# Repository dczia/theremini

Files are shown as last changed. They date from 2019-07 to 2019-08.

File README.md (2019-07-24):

# Theremini

What's better than a laser theremin?  How about a laser theremin SAO?!

This SAO unfortunately does not make any noise or produce lasers, but it does have:

 - Microchip AVR attiny1616 8-bit microcontroller
 - 5 touch-sensitive buttons
 - 6 red LEDs arranged about the tape spool holes
 - Reprogrammable via UPDI via the SAO connector!

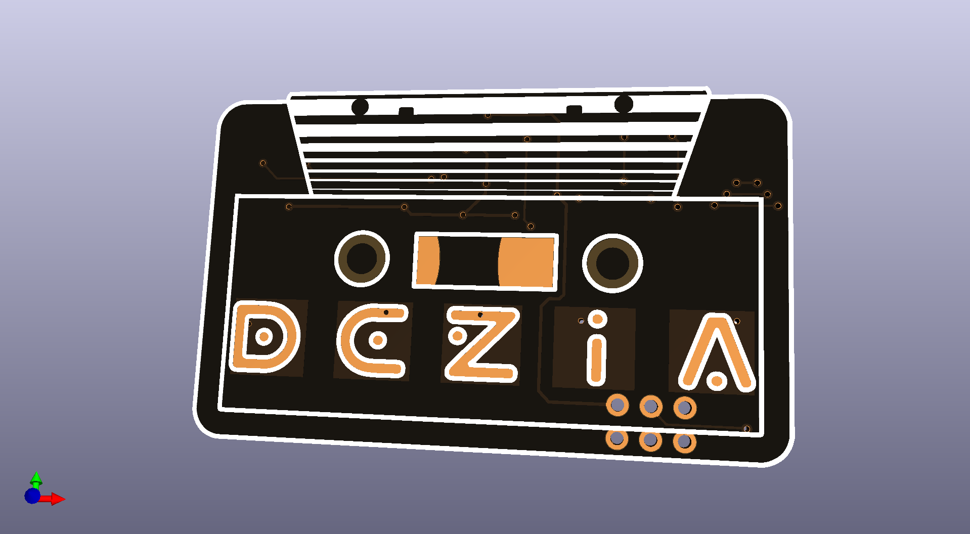
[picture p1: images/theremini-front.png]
Theremini Front


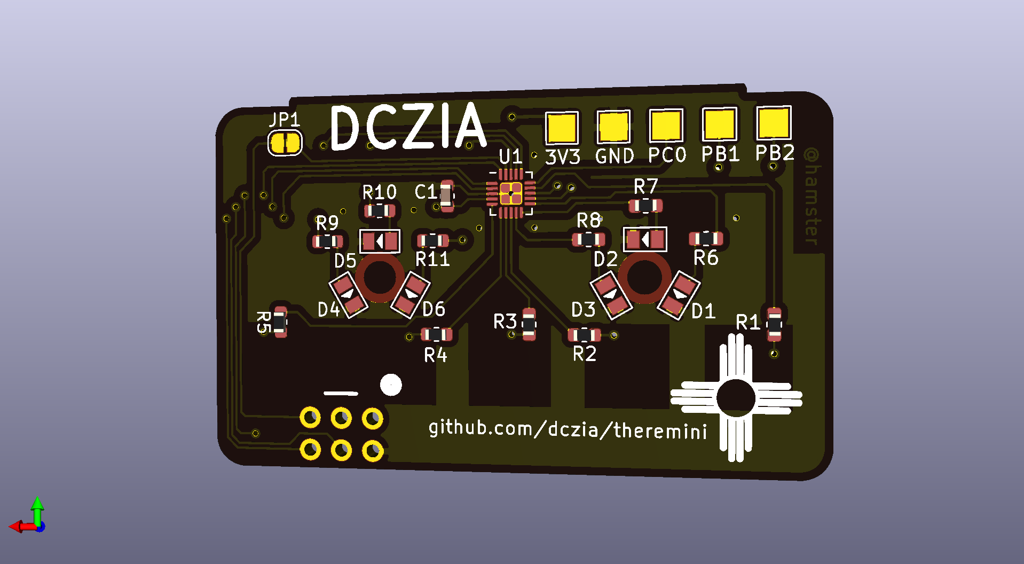
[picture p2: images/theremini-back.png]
Theremini back


Use avr-gcc to compile the code - just run a 'make'

You'll need a UPDI programmer to program this guy.  I modded a 'ATTINY817 XPLAINED MINI' board to use as a programmer. See [this link](https://www.jsykora.info/2019/04/avr-updi-programmer-from-attiny817-xplained-mini/) for a howto.

Gerbers are included - the panel directory is the panel I actually ordered.

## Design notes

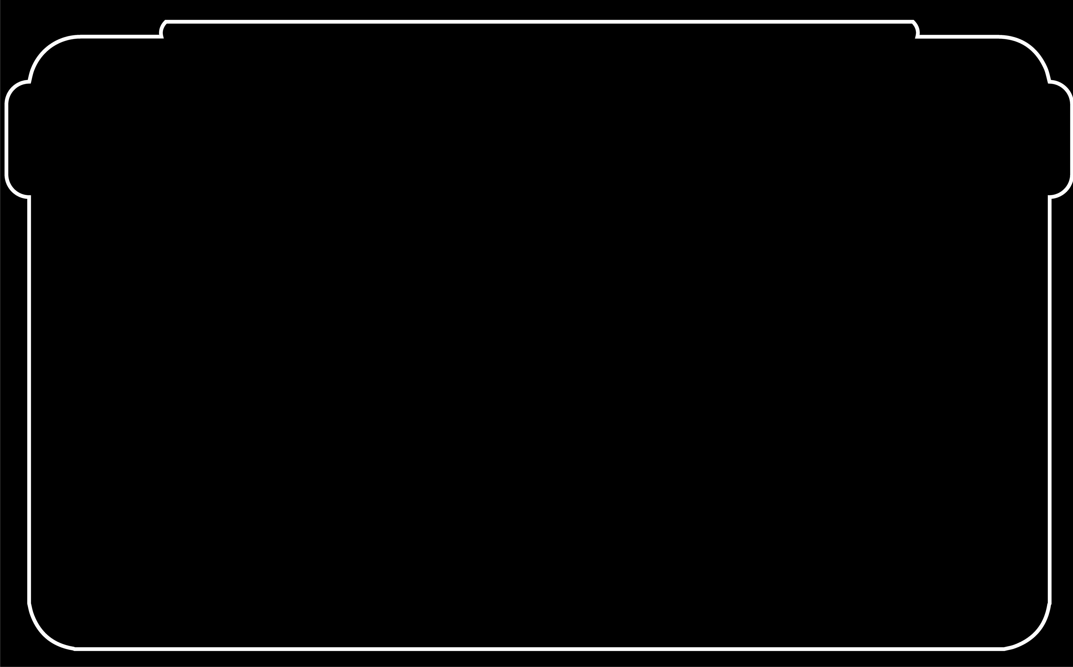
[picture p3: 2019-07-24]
images/laser-theremin-05.png

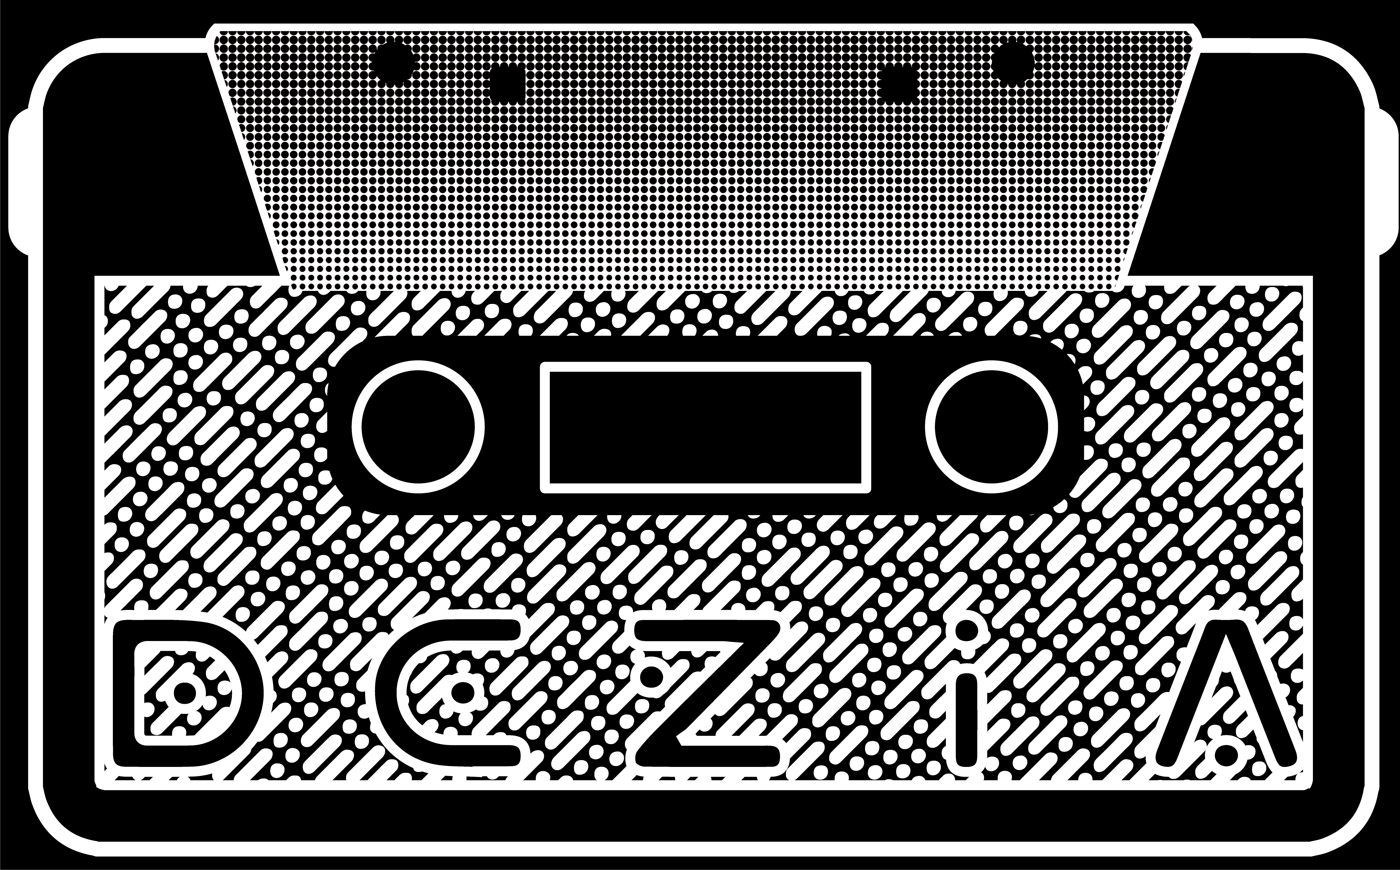
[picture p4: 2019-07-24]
images/laser-theremin-01.png

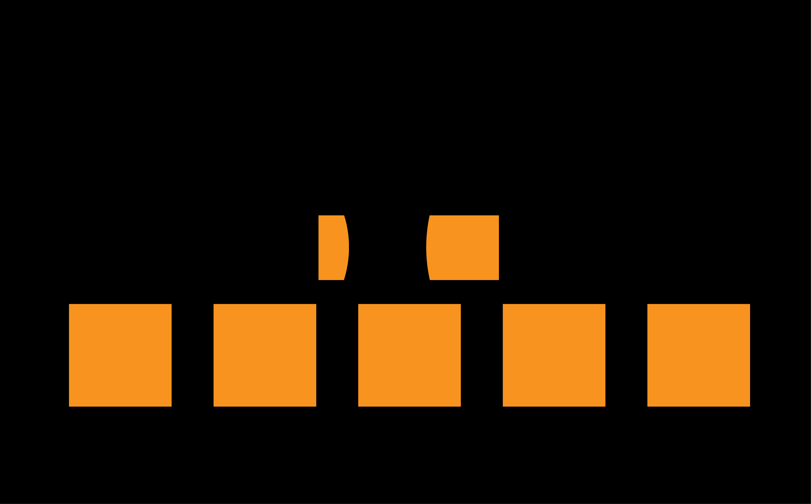
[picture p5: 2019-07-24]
images/laser-theremin-03.png

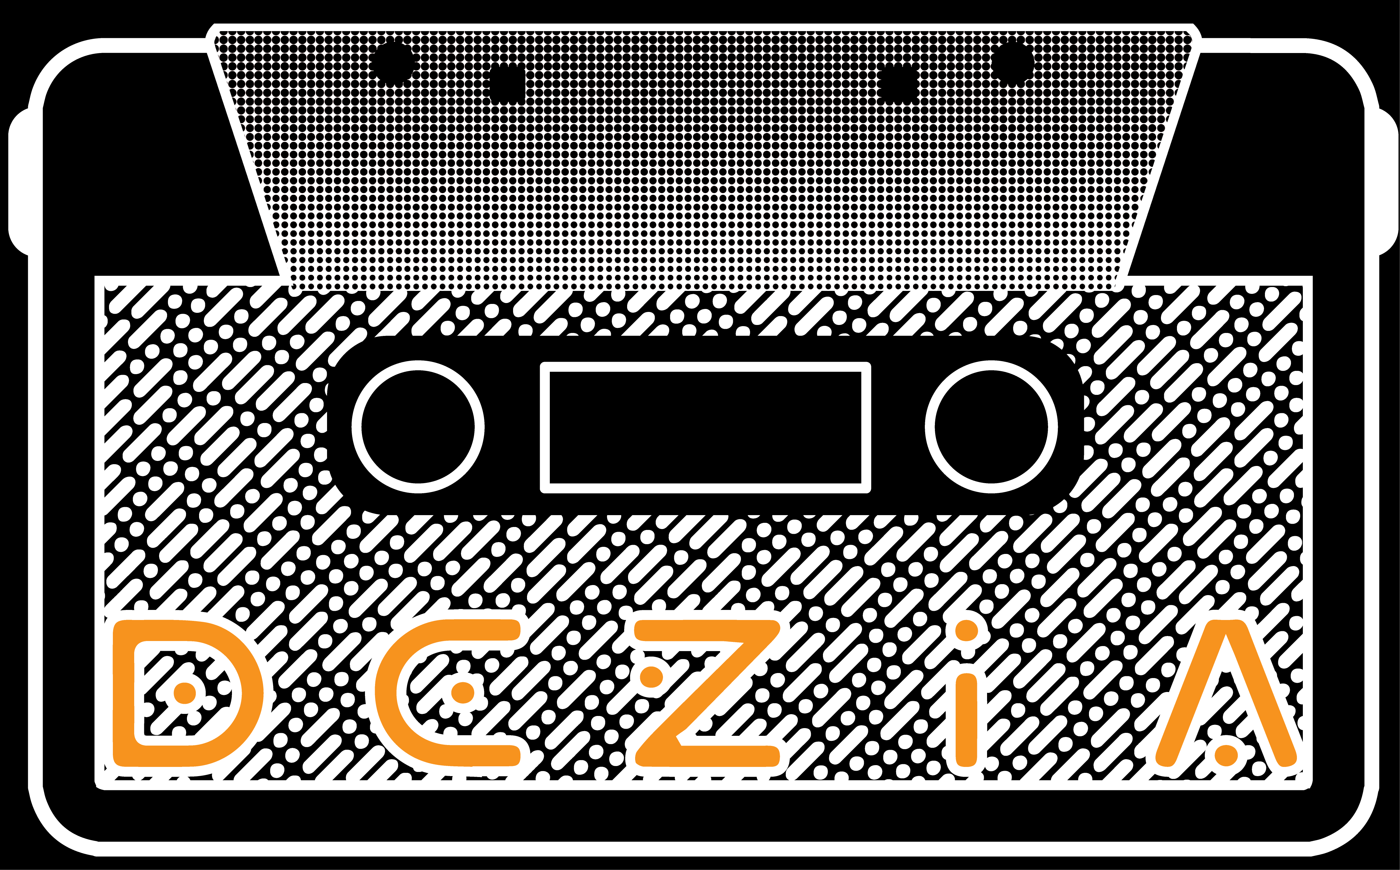
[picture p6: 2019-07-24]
images/laser-theremin-02.png

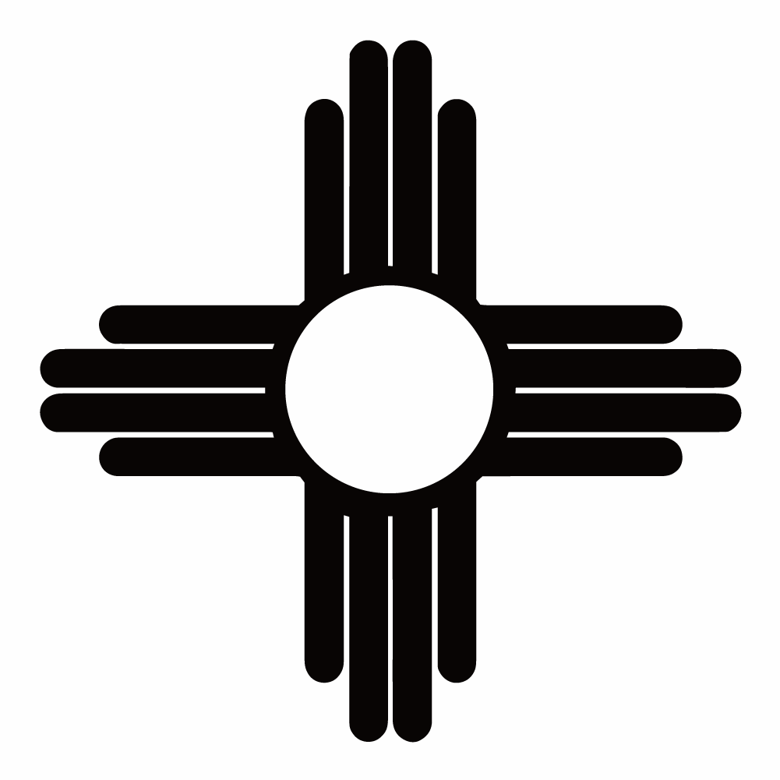
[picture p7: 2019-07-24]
images/zia.png

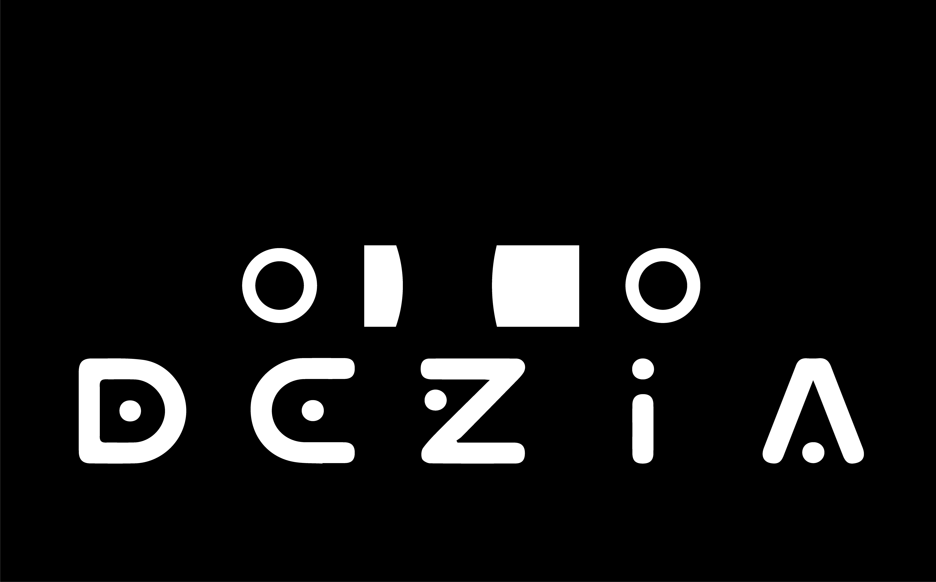
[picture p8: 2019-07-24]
images/laser-theremin-04.png

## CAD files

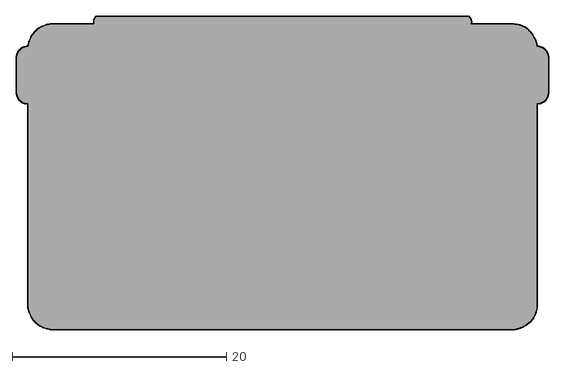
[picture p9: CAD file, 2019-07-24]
images/laser-theremin.dxf
49.7 x 29.2

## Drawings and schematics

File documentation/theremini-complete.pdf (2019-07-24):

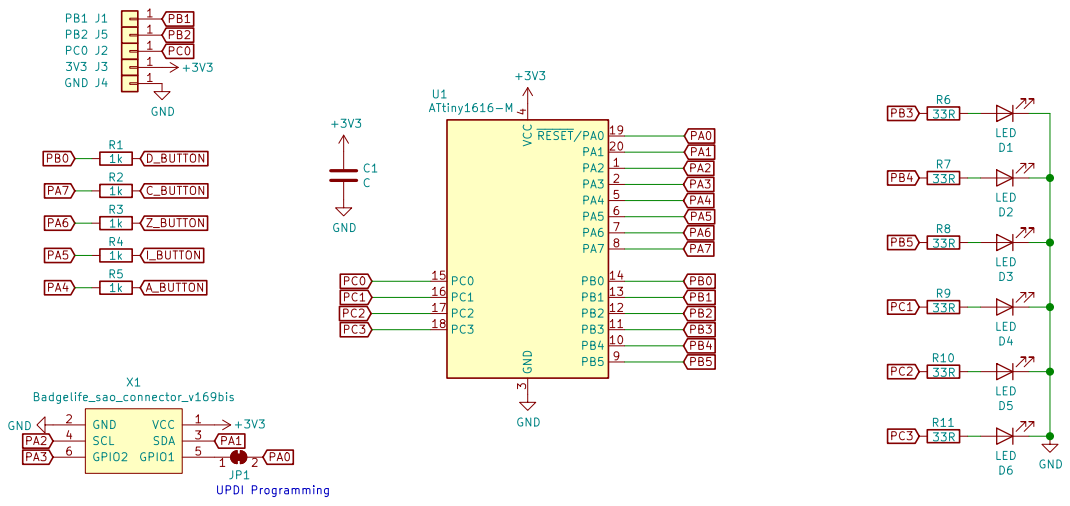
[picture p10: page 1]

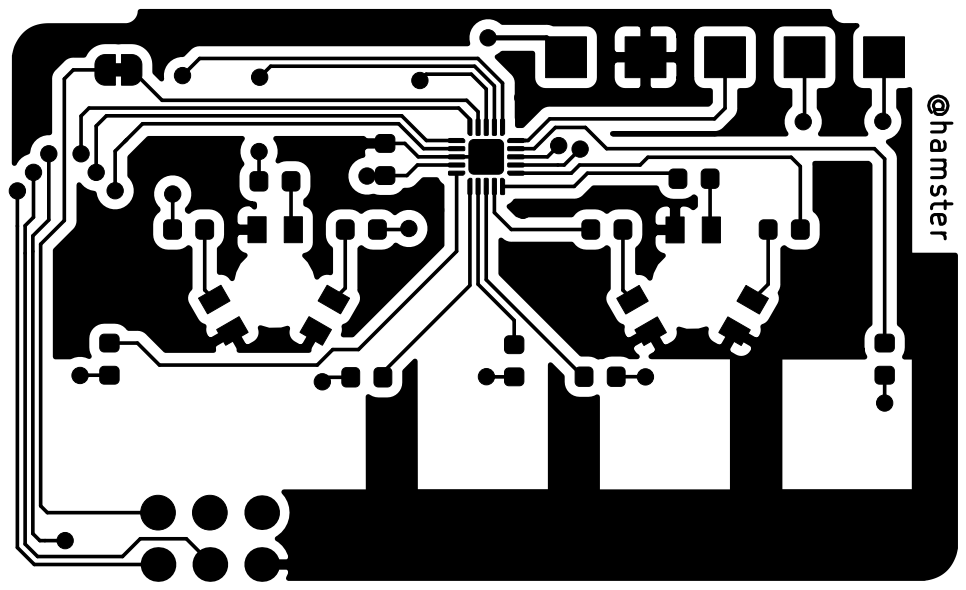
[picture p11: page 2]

File: theremini.kicad_pcb Sheet: DCZia @hamster @hamster

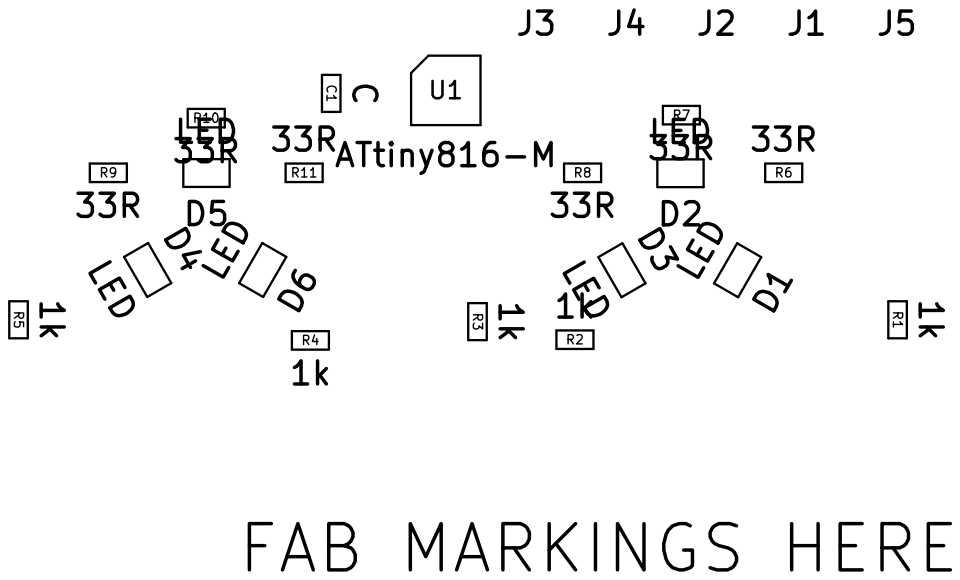
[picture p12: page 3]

File: theremini.kicad_pcb Sheet: DCZia @hamster

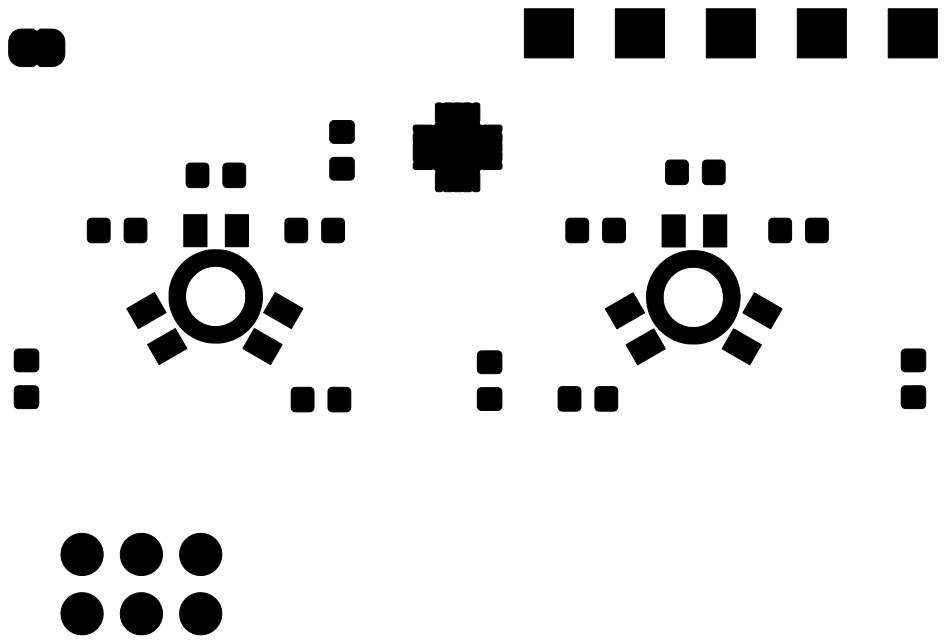
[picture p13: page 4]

File: theremini.kicad_pcb Sheet: DCZia @hamster

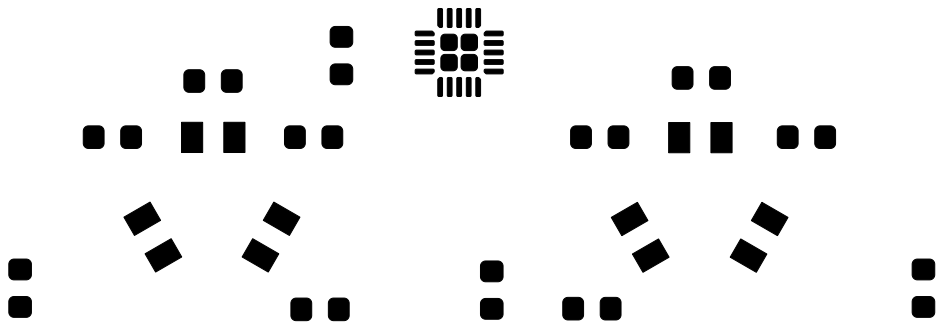
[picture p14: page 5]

File: theremini.kicad_pcb Sheet: DCZia @hamster

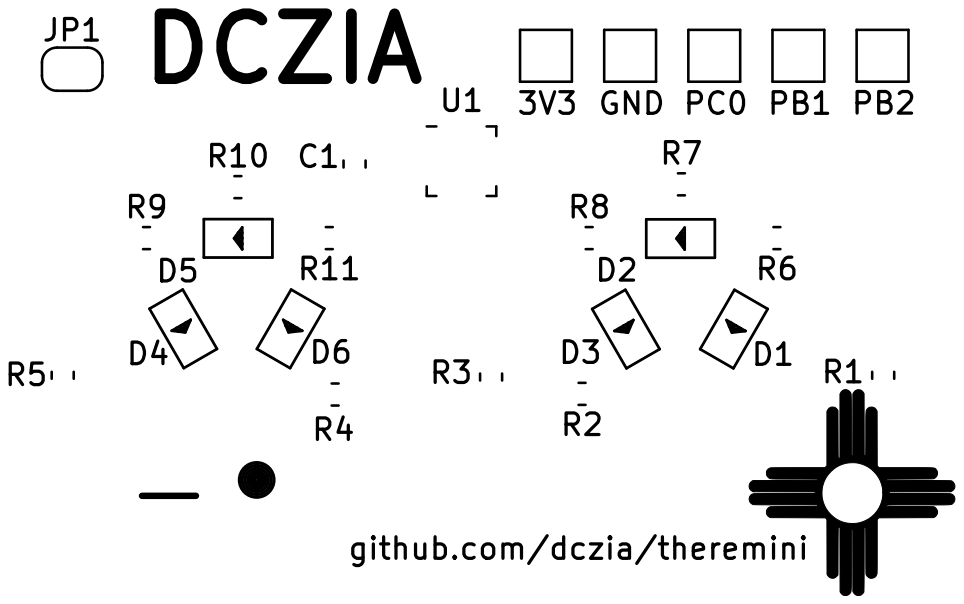
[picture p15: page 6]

File: theremini.kicad_pcb Sheet: DCZia @hamster

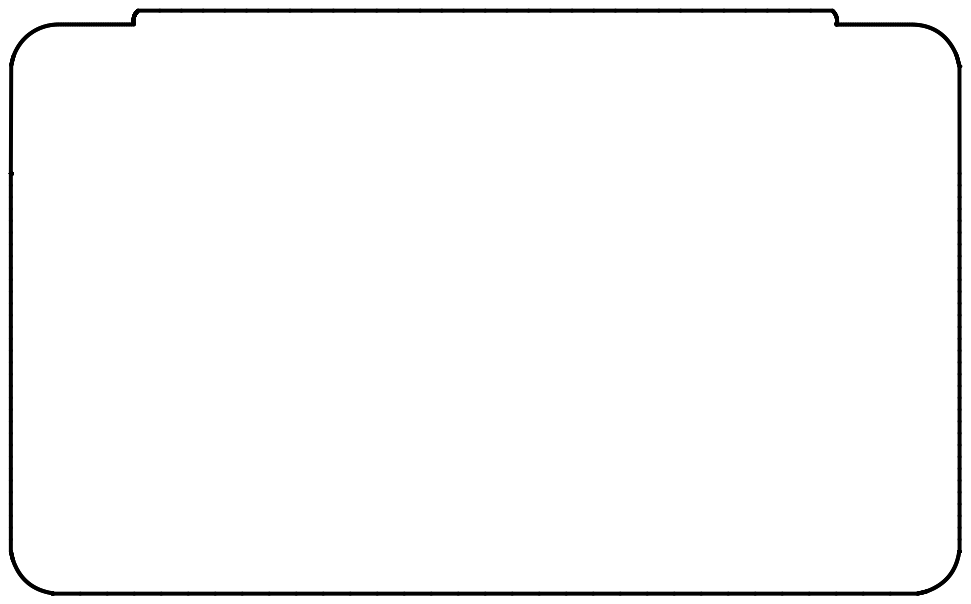
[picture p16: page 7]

File: theremini.kicad_pcb Sheet: DCZia @hamster

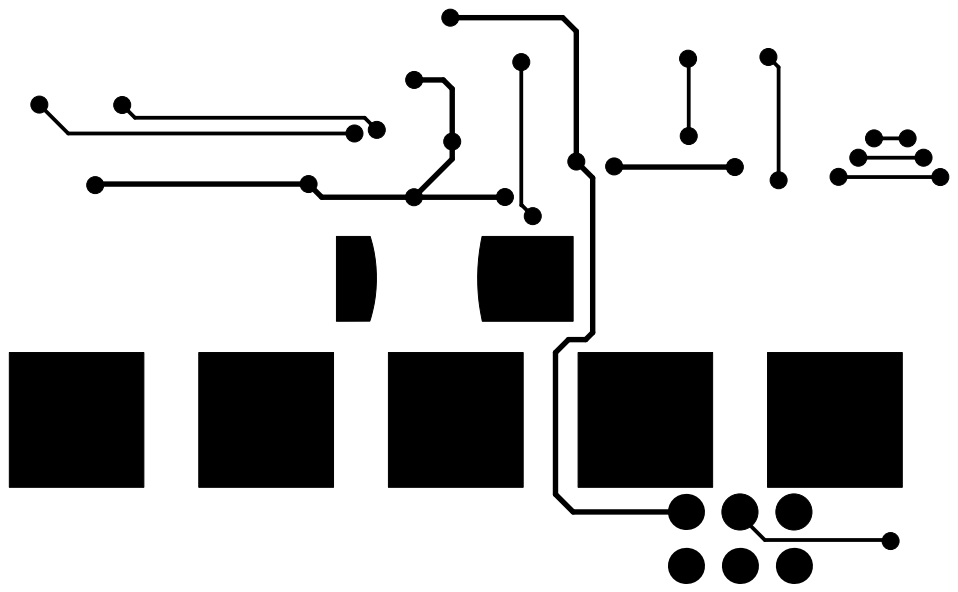
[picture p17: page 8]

File: theremini.kicad_pcb Sheet: DCZia @hamster

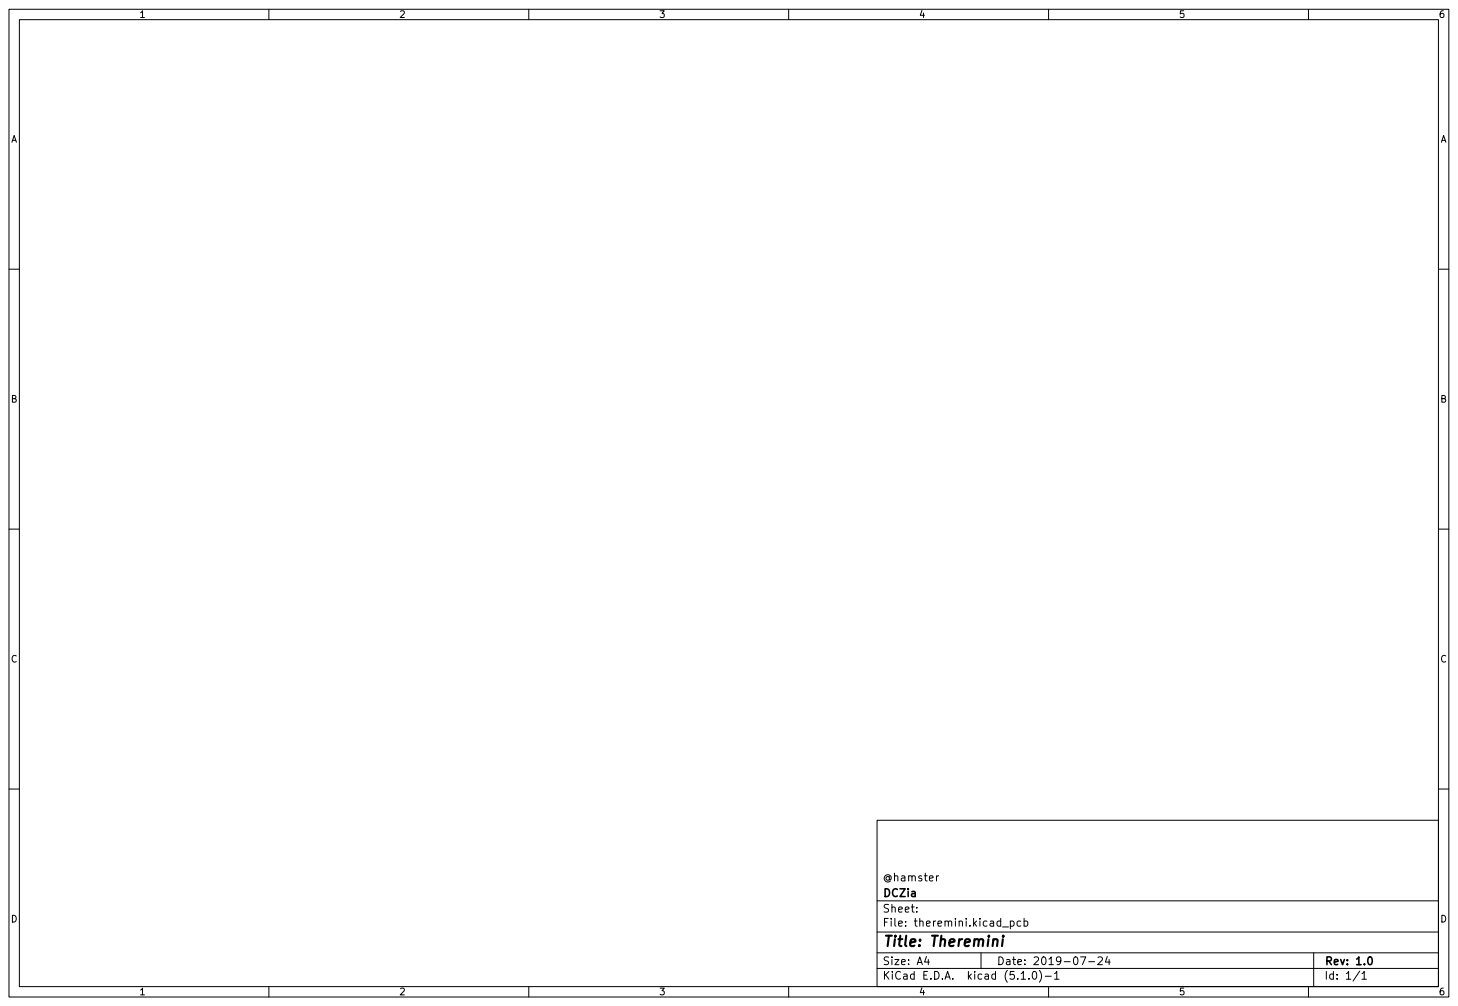
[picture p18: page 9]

File: theremini.kicad_pcb Sheet: DCZia @hamster

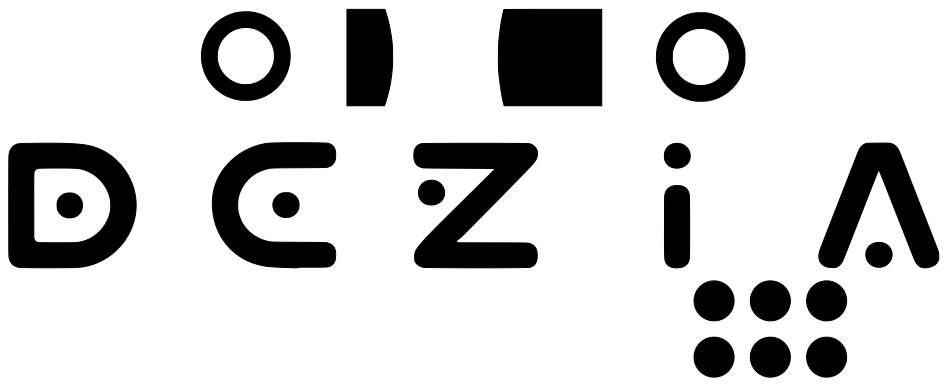
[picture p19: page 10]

File: theremini.kicad_pcb Sheet: DCZia @hamster

File: theremini.kicad_pcb Sheet: DCZia @hamster

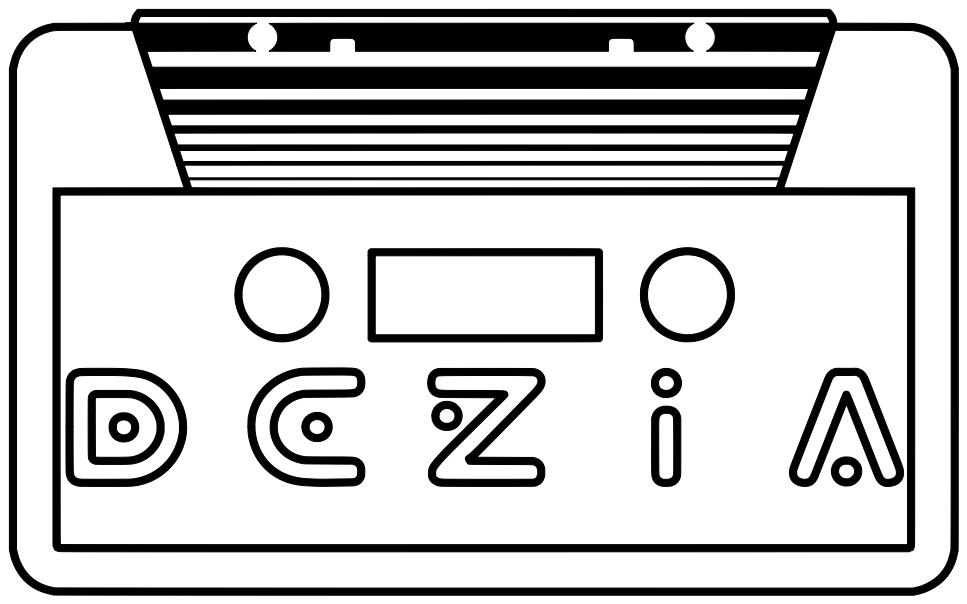
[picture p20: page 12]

File: theremini.kicad_pcb Sheet: DCZia @hamster

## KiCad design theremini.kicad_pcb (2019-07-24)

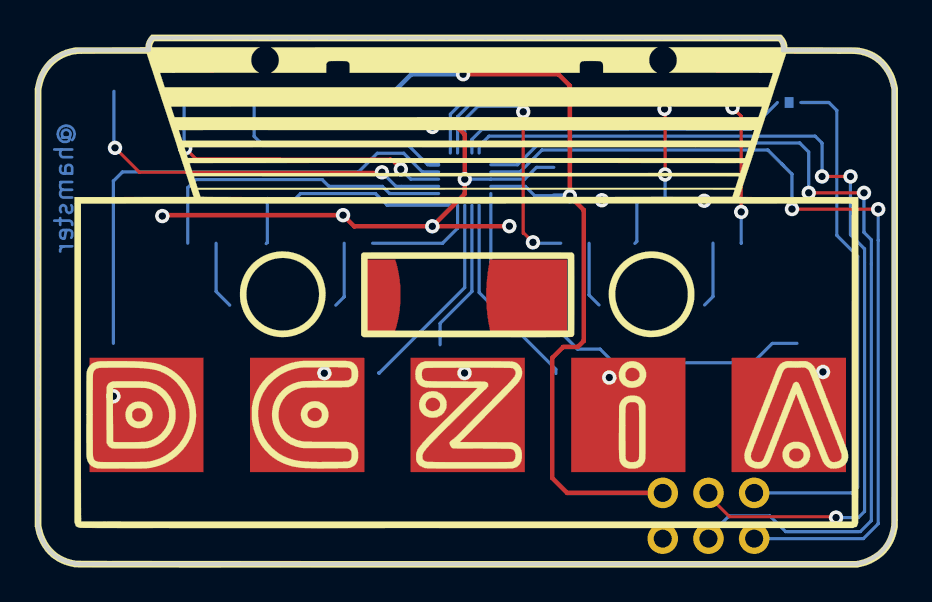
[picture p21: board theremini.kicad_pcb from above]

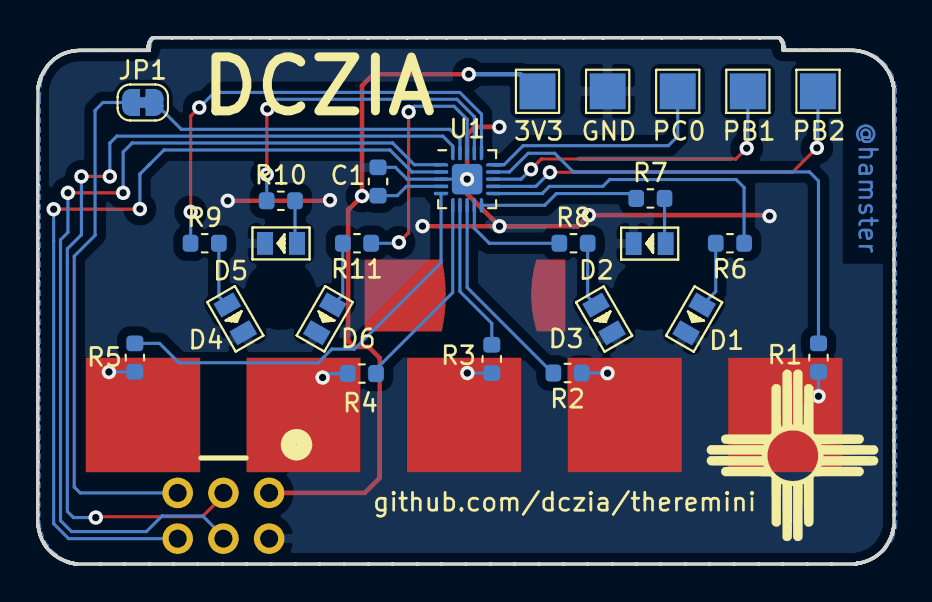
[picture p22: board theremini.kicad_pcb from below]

Board: 2 copper layers, 47.6 x 29.2 mm, 26 parts (25 on the bottom side), 27 nets.

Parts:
C1: C; C_0603_1608Metric
D1, D2, D3, D4, D5, D6: LED; LED-0805
J1: PB1; TestPoint_Pad_2.0x2.0mm
J2: PC0; TestPoint_Pad_2.0x2.0mm
J3: 3V3; TestPoint_Pad_2.0x2.0mm
J4: GND; TestPoint_Pad_2.0x2.0mm
J5: PB2; TestPoint_Pad_2.0x2.0mm
JP1: SolderJumper_2_Bridged; SolderJumper-2_P1.3mm_Bridged_RoundedPad1.0x1.5mm
R1, R2, R3, R4, R5: 1k; R_0603_1608Metric
R6, R7, R8, R9, R10, R11: 33R; R_0603_1608Metric
U1: ATtiny816-M; VQFN-20-1EP_3x3mm_P0.4mm_EP1.7x1.7mm
X1: Badgelife_sao_connector_v169bis; Badgelife-Shitty-v1.69bis

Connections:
+3V3: C1.1, J3.1, U1.4, X1.1
GND: C1.2, D1.1, D2.1, D3.1, D4.1, D5.1, D6.1, J4.1, U1.3, U1.21, X1.2
unnamed: D1.2, R6.2
unnamed: D2.2, R7.2
unnamed: D3.2, R8.2
unnamed: D4.2, R9.2
unnamed: D5.2, R10.2
unnamed: D6.2, R11.2
unnamed: JP1.1, X1.5
PA0: JP1.2, U1.19
PA1: U1.20, X1.3
PA2: U1.1, X1.4
PA3: U1.2, X1.6
PA4: R5.2, U1.5
PA5: R4.2, U1.6
PA6: R3.2, U1.7
PA7: R2.2, U1.8
PB0: R1.2, U1.14
PB1: J1.1, U1.13
PB2: J5.1, U1.12
PB3: R6.1, U1.11
PB4: R7.1, U1.10
PB5: R8.1, U1.9
PC0: J2.1, U1.15
PC1: R9.1, U1.16
PC2: R10.1, U1.17
PC3: R11.1, U1.18

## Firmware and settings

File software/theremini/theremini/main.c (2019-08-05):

#define F_CPU 20000000

#include <atmel_start.h>
#include <util/delay.h>

extern volatile uint8_t measurement_done_touch;
extern volatile uint8_t LED_PWM[6];
extern volatile uint16_t timeTicks;

// Logarithmic brightness levels
const uint8_t pwm_log[] = {30,43,59,78,102,137,196,255};

KEYPRESS keyPress[5] = { 0 };
CAPKEY lastKey = KEY_NONE;

int main(void){
	
	/* Initializes MCU, drivers and middleware */
	system_init();
	touch_init();
	
	I2C_0_slave_init();
	
	cpu_irq_enable(); /* Global Interrupt Enable */


	LED1_set_level(true);
	_delay_ms(50);
	LED2_set_level(true);
	_delay_ms(50);
	LED3_set_level(true);
	_delay_ms(50);
	LED4_set_level(true);
	_delay_ms(50);
	LED5_set_level(true);
	_delay_ms(50);
	LED6_set_level(true);
	_delay_ms(200);
	
	LED1_set_level(false);
	_delay_ms(50);
	LED2_set_level(false);
	_delay_ms(50);
	LED3_set_level(false);
	_delay_ms(50);
	LED4_set_level(false);
	_delay_ms(50);
	LED5_set_level(false);
	_delay_ms(50);
	LED6_set_level(false);
	_delay_ms(50);

	TIMER_0_init();
	
	LED_PWM[0] = 14;
	LED_PWM[1] = 14;
	LED_PWM[2] = 14;
	LED_PWM[3] = 14;
	LED_PWM[4] = 14;
	LED_PWM[5] = 14;
	
	RUNMODE mode = MODE_SPOOLING;
	RUNMODE oldMode = MODE_SPOOLING;
	bool touching = false;
	bool changed = false;
	
	uint8_t step = 0;
	uint8_t delay = 0;
	uint8_t delayTop = 100;
	uint8_t counter = 0;
	uint8_t side = 0;

	/* Replace with your application code */
	while (1) {
		
		touch_process();
		if(measurement_done_touch == 1){
			////touchCheck(&touching, &changed);
			if((get_sensor_state(KEY_D) & KEY_TOUCHED_MASK) != 0){
				keyPress[KEY_D].touched = true;
				touching = true;
			}
			else{
				if(keyPress[KEY_D].touched){
					keyPress[KEY_D].touched = false;
					keyPress[KEY_D].latched = true;
					changed = true;
					lastKey = KEY_D;
					mode = MODE_SPOOLING;
				}
			}
			
			if((get_sensor_state(KEY_C) & KEY_TOUCHED_MASK) != 0){
				keyPress[KEY_C].touched = true;
				touching = true;
			}
			else{
				if(keyPress[KEY_C].touched){
					keyPress[KEY_C].touched = false;
					keyPress[KEY_C].latched = true;
					changed = true;
					lastKey = KEY_C;
					mode = MODE_HAZARDS;
				}
			}
			
			if((get_sensor_state(KEY_Z) & KEY_TOUCHED_MASK) != 0){
				keyPress[KEY_Z].touched = true;
				touching = true;
			}
			else{
				if(keyPress[KEY_Z].touched){
					keyPress[KEY_Z].touched = false;
					keyPress[KEY_Z].latched = true;
					changed = true;
					lastKey = KEY_Z;
					mode = MODE_FLICKER;
				}
			}
			
			if((get_sensor_state(KEY_I) & KEY_TOUCHED_MASK) != 0){
				keyPress[KEY_I].touched = true;
				touching = true;
			}
			else{
				if(keyPress[KEY_I].touched){
					keyPress[KEY_I].touched = false;
					keyPress[KEY_I].latched = true;
					changed = true;
					lastKey = KEY_I;
					mode = MODE_RANDOM;
				}
			}
			
			if((get_sensor_state(KEY_A) & KEY_TOUCHED_MASK) != 0){
				keyPress[KEY_A].touched = true;
				touching = true;
			}
			else{
				if(keyPress[KEY_A].touched){
					keyPress[KEY_A].touched = false;
					keyPress[KEY_A].latched = true;
					changed = true;
					lastKey = KEY_A;
					mode = MODE_REVERSE_SPOOLING;
				}
			}
		}

		if(!touching){
			if(changed){
				// Change mode
				changed = false;
				for(uint8_t i = 0; i < 6; i++){
					LED_PWM[i] = 14;
				}
				
				counter = 0;
				delay = 0;
				step = 0;
				
				if(oldMode == mode){
					delayTop = delayTop / 2;
					if(delayTop < 8){
						delayTop = 100;
					}
				}
				oldMode = mode;
			}
			
			// Update animation
			switch(mode){
				case MODE_SPOOLING:
					if(delay == 0){
						switch(step){
							case 0:
							LED_PWM[2] = 0;
							LED_PWM[3] = 0;
						
							LED_PWM[0] = 184;
							LED_PWM[5] = 184;
							step = 1;
							delay = delayTop;
							break;
							case 1:
							LED_PWM[0] = 0;
							LED_PWM[5] = 0;
						
							LED_PWM[1] = 184;
							LED_PWM[4] = 184;
							step = 2;
							delay = delayTop;
							break;
							case 2:
							LED_PWM[1] = 0;
							LED_PWM[4] = 0;
						
							LED_PWM[2] = 184;
							LED_PWM[3] = 184;
							step = 0;
							delay = delayTop;
							break;
						}
					}
					else{
						delay--;
					}
				
					break;
				case MODE_HAZARDS:
					if(delay == 0){
						if((counter % 2) == 0){
							if(side == 0){
								LED_PWM[0] = 14;
								LED_PWM[1] = 14;
								LED_PWM[2] = 14;
								LED_PWM[3] = 184;
								LED_PWM[4] = 184;
								LED_PWM[5] = 184;
								side = 1;
							}
							else{
								LED_PWM[0] = 184;
								LED_PWM[1] = 184;
								LED_PWM[2] = 184;
								LED_PWM[3] = 14;
								LED_PWM[4] = 14;
								LED_PWM[5] = 14;
								side = 0;
							}
						}
						counter++;
						delay = delayTop;
					}
					delay--;
					break;
				case MODE_FLICKER:	
					if((delay == 0)){	
						for(uint8_t i = 0; i < 6; i++){
							if(i == step){
								LED_PWM[i] = 184;
							}
							else{
								LED_PWM[i] = 14;
							}
						}
						step++;
						if(step > 5){
							step = 0;
						}
						delay = delayTop;
					}
					else{
						delay--;
					}
					break;
				case MODE_RANDOM:
					if(delay == 0){
						LED_PWM[0] = rand() % 184;
						LED_PWM[1] = rand() % 184;
						LED_PWM[2] = rand() % 184;
						LED_PWM[3] = rand() % 184;
						LED_PWM[4] = rand() % 184;
						LED_PWM[5] = rand() % 184;
						delay = delayTop;
					}
					else{
						delay--;
					}
					break;
				case MODE_REVERSE_SPOOLING:
					if(delay == 0){
						switch(step){
							case 0:
								LED_PWM[1] = 0;
								LED_PWM[4] = 0;
											
								LED_PWM[0] = 184;
								LED_PWM[5] = 184;
								step = 1;
								delay = delayTop;
								break;
							case 1:
								LED_PWM[0] = 0;
								LED_PWM[5] = 0;
								
								LED_PWM[2] = 184;
								LED_PWM[3] = 184;
								
								step = 2;
								delay = delayTop;
								break;
							case 2:
								LED_PWM[2] = 0;
								LED_PWM[3] = 0;

								LED_PWM[1] = 184;
								LED_PWM[4] = 184;
								step = 0;
								delay = delayTop;
								break;
						}
					}
					else{
						delay--;
					}
					break;
			}
		}
		else{
			touching = false;
			// Mode is about to change, light up all the LEDs
			for(uint8_t i = 0; i < 5; i++){
				LED_PWM[i] = 184;
			}
			_delay_ms(20);
		}
		
		_delay_ms(1);

	}
}

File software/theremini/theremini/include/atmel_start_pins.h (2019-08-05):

/*
 * Code generated from START.
 *
 * This file will be overwritten when reconfiguring your START project.
 * Please copy examples or other code you want to keep to a separate file
 * to avoid losing it when reconfiguring.
 */
#ifndef ATMEL_START_PINS_H_INCLUDED
#define ATMEL_START_PINS_H_INCLUDED

#include <port.h>

/**
 * \brief Set PA1 pull mode
 *
 * Configure pin to pull up, down or disable pull mode, supported pull
 * modes are defined by device used
 *
 * \param[in] pull_mode Pin pull mode
 */
static inline void PA1_set_pull_mode(const enum port_pull_mode pull_mode)
{
	PORTA_set_pin_pull_mode(1, pull_mode);
}

/**
 * \brief Set PA1 data direction
 *
 * Select if the pin data direction is input, output or disabled.
 * If disabled state is not possible, this function throws an assert.
 *
 * \param[in] direction PORT_DIR_IN  = Data direction in
 *                      PORT_DIR_OUT = Data direction out
 *                      PORT_DIR_OFF = Disables the pin
 *                      (low power state)
 */
static inline void PA1_set_dir(const enum port_dir dir)
{
	PORTA_set_pin_dir(1, dir);
}

/**
 * \brief Set PA1 input/sense configuration
 *
 * Enable/disable PA1 digital input buffer and pin change interrupt,
 * select pin interrupt edge/level sensing mode
 *
 * \param[in] isc PORT_ISC_INTDISABLE_gc    = Iterrupt disabled but input buffer enabled
 *                PORT_ISC_BOTHEDGES_gc     = Sense Both Edges
 *                PORT_ISC_RISING_gc        = Sense Rising Edge
 *                PORT_ISC_FALLING_gc       = Sense Falling Edge
 *                PORT_ISC_INPUT_DISABLE_gc = Digital Input Buffer disabled
 *                PORT_ISC_LEVEL_gc         = Sense low Level
 */
static inline void PA1_set_isc(const PORT_ISC_t isc)
{
	PORTA_pin_set_isc(1, isc);
}

/**
 * \brief Set PA1 inverted mode
 *
 * Enable or disable inverted I/O on a pin
 *
 * \param[in] inverted true  = I/O on PA1 is inverted
 *                     false = I/O on PA1 is not inverted
 */
static inline void PA1_set_inverted(const bool inverted)
{
	PORTA_pin_set_inverted(1, inverted);
}

/**
 * \brief Set PA1 level
 *
 * Sets output level on a pin
 *
 * \param[in] level true  = Pin level set to "high" state
 *                  false = Pin level set to "low" state
 */
static inline void PA1_set_level(const bool level)
{
	PORTA_set_pin_level(1, level);
}

/**
 * \brief Toggle output level on PA1
 *
 * Toggle the pin level
 */
static inline void PA1_toggle_level()
{
	PORTA_toggle_pin_level(1);
}

/**
 * \brief Get level on PA1
 *
 * Reads the level on a pin
 */
static inline bool PA1_get_level()
{
	return PORTA_get_pin_level(1);
}

/**
 * \brief Set PA2 pull mode
 *
 * Configure pin to pull up, down or disable pull mode, supported pull
 * modes are defined by device used
 *
 * \param[in] pull_mode Pin pull mode
 */
static inline void PA2_set_pull_mode(const enum port_pull_mode pull_mode)
{
	PORTA_set_pin_pull_mode(2, pull_mode);
}

/**
 * \brief Set PA2 data direction
 *
 * Select if the pin data direction is input, output or disabled.
 * If disabled state is not possible, this function throws an assert.
 *
 * \param[in] direction PORT_DIR_IN  = Data direction in
 *                      PORT_DIR_OUT = Data direction out
 *                      PORT_DIR_OFF = Disables the pin
 *                      (low power state)
 */
static inline void PA2_set_dir(const enum port_dir dir)
{
	PORTA_set_pin_dir(2, dir);
}

/**
 * \brief Set PA2 input/sense configuration
 *
 * Enable/disable PA2 digital input buffer and pin change interrupt,
 * select pin interrupt edge/level sensing mode
 *
 * \param[in] isc PORT_ISC_INTDISABLE_gc    = Iterrupt disabled but input buffer enabled
 *                PORT_ISC_BOTHEDGES_gc     = Sense Both Edges
 *                PORT_ISC_RISING_gc        = Sense Rising Edge
 *                PORT_ISC_FALLING_gc       = Sense Falling Edge
 *                PORT_ISC_INPUT_DISABLE_gc = Digital Input Buffer disabled
 *                PORT_ISC_LEVEL_gc         = Sense low Level
 */
static inline void PA2_set_isc(const PORT_ISC_t isc)
{
	PORTA_pin_set_isc(2, isc);
}

/**
 * \brief Set PA2 inverted mode
 *
 * Enable or disable inverted I/O on a pin
 *
 * \param[in] inverted true  = I/O on PA2 is inverted
 *                     false = I/O on PA2 is not inverted
 */
static inline void PA2_set_inverted(const bool inverted)
{
	PORTA_pin_set_inverted(2, inverted);
}

/**
 * \brief Set PA2 level
 *
 * Sets output level on a pin
 *
 * \param[in] level true  = Pin level set to "high" state
 *                  false = Pin level set to "low" state
 */
static inline void PA2_set_level(const bool level)
{
	PORTA_set_pin_level(2, level);
}

/**
 * \brief Toggle output level on PA2
 *
 * Toggle the pin level
 */
static inline void PA2_toggle_level()
{
	PORTA_toggle_pin_level(2);
}

/**
 * \brief Get level on PA2
 *
 * Reads the level on a pin
 */
static inline bool PA2_get_level()
{
	return PORTA_get_pin_level(2);
}

/**
 * \brief Set GPIO2 pull mode
 *
 * Configure pin to pull up, down or disable pull mode, supported pull
 * modes are defined by device used
 *
 * \param[in] pull_mode Pin pull mode
 */
static inline void GPIO2_set_pull_mode(const enum port_pull_mode pull_mode)
{
	PORTA_set_pin_pull_mode(3, pull_mode);
}

/**
 * \brief Set GPIO2 data direction
 *
 * Select if the pin data direction is input, output or disabled.
 * If disabled state is not possible, this function throws an assert.
 *
 * \param[in] direction PORT_DIR_IN  = Data direction in
 *                      PORT_DIR_OUT = Data direction out
 *                      PORT_DIR_OFF = Disables the pin
 *                      (low power state)
 */
static inline void GPIO2_set_dir(const enum port_dir dir)
{
	PORTA_set_pin_dir(3, dir);
}

/**
 * \brief Set GPIO2 input/sense configuration
 *
 * Enable/disable GPIO2 digital input buffer and pin change interrupt,
 * select pin interrupt edge/level sensing mode
 *
 * \param[in] isc PORT_ISC_INTDISABLE_gc    = Iterrupt disabled but input buffer enabled
 *                PORT_ISC_BOTHEDGES_gc     = Sense Both Edges
 *                PORT_ISC_RISING_gc        = Sense Rising Edge
 *                PORT_ISC_FALLING_gc       = Sense Falling Edge
 *                PORT_ISC_INPUT_DISABLE_gc = Digital Input Buffer disabled
 *                PORT_ISC_LEVEL_gc         = Sense low Level
 */
static inline void GPIO2_set_isc(const PORT_ISC_t isc)
{
	PORTA_pin_set_isc(3, isc);
}

/**
 * \brief Set GPIO2 inverted mode
 *
 * Enable or disable inverted I/O on a pin
 *
 * \param[in] inverted true  = I/O on GPIO2 is inverted
 *                     false = I/O on GPIO2 is not inverted
 */
static inline void GPIO2_set_inverted(const bool inverted)
{
	PORTA_pin_set_inverted(3, inverted);
}
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

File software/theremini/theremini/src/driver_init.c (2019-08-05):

/**
 * \file
 *
 * \brief Driver initialization.
 *
 (c) 2018 Microchip Technology Inc. and its subsidiaries.

    Subject to your compliance with these terms,you may use this software and
    any derivatives exclusively with Microchip products.It is your responsibility
    to comply with third party license terms applicable to your use of third party
    software (including open source software) that may accompany Microchip software.

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
    IN NO EVENT WILL MICROCHIP BE LIABLE FOR ANY INDIRECT, SPECIAL, PUNITIVE,
    INCIDENTAL OR CONSEQUENTIAL LOSS, DAMAGE, COST OR EXPENSE OF ANY KIND
    WHATSOEVER RELATED TO THE SOFTWARE, HOWEVER CAUSED, EVEN IF MICROCHIP HAS
    BEEN ADVISED OF THE POSSIBILITY OR THE DAMAGES ARE FORESEEABLE. TO THE
    FULLEST EXTENT ALLOWED BY LAW, MICROCHIP'S TOTAL LIABILITY ON ALL CLAIMS IN
    ANY WAY RELATED TO THIS SOFTWARE WILL NOT EXCEED THE AMOUNT OF FEES, IF ANY,
    THAT YOU HAVE PAID DIRECTLY TO MICROCHIP FOR THIS SOFTWARE.
 *
 */

/*
 * Code generated by START.
 *
 * This file will be overwritten when reconfiguring your START project.
 * Please copy examples or other code you want to keep to a separate file
 * to avoid losing it when reconfiguring.
 */

#include "driver_init.h"
#include <system.h>
#include <tca.h>
#include <tcb.h>

void TIMER_0_initialization(void)
{

	TIMER_0_init();
}

void TIMER_1_initialization(void)
{

	TIMER_1_init();
}

/* configure pins and initialize registers */
void I2C_0_initialization(void)
{

	PA2_set_dir(
	    // <y> Pin direction
	    // <id> pad_dir
	    // <PORT_DIR_OFF"> Off
	    // <PORT_DIR_IN"> In
	    // <PORT_DIR_OUT"> Out
	    PORT_DIR_OUT);

	PA2_set_level(
	    // <y> Initial level
	    // <id> pad_initial_level
	    // <false"> Low
	    // <true"> High
	    false);

	PA2_set_pull_mode(
	    // <y> Pull configuration
	    // <id> pad_pull_config
	    // <PORT_PULL_OFF"> Off
	    // <PORT_PULL_UP"> Pull-up
	    PORT_PULL_OFF);

	PA2_set_inverted(
	    // <y> Invert I/O on pin
	    // <id> pad_invert
	    // <false"> Not inverted
	    // <true"> Inverted
	    false);

	PA2_set_isc(
	    // <y> Pin Input/Sense Configuration
	    // <id> pad_isc
	    // <PORT_ISC_INTDISABLE_gc"> Interrupt disabled but input buffer enabled
	    // <PORT_ISC_BOTHEDGES_gc"> Sense Both Edges
	    // <PORT_ISC_RISING_gc"> Sense Rising Edge
	    // <PORT_ISC_FALLING_gc"> Sense Falling Edge
	    // <PORT_ISC_INPUT_DISABLE_gc"> Digital Input Buffer disabled
	    // <PORT_ISC_LEVEL_gc"> Sense low Level
	    PORT_ISC_INTDISABLE_gc);

	/* set the alternate pin mux */
	PORTMUX.CTRLB |= PORTMUX_TWI0_bm;

	PA1_set_dir(
	    // <y> Pin direction
	    // <id> pad_dir
	    // <PORT_DIR_OFF"> Off
	    // <PORT_DIR_IN"> In
	    // <PORT_DIR_OUT"> Out
	    PORT_DIR_OUT);

	PA1_set_level(
	    // <y> Initial level
	    // <id> pad_initial_level
	    // <false"> Low
	    // <true"> High
	    false);

	PA1_set_pull_mode(
	    // <y> Pull configuration
	    // <id> pad_pull_config
	    // <PORT_PULL_OFF"> Off
	    // <PORT_PULL_UP"> Pull-up
	    PORT_PULL_OFF);

	PA1_set_inverted(
	    // <y> Invert I/O on pin
	    // <id> pad_invert
	    // <false"> Not inverted
	    // <true"> Inverted
	    false);

	PA1_set_isc(
	    // <y> Pin Input/Sense Configuration
	    // <id> pad_isc
	    // <PORT_ISC_INTDISABLE_gc"> Interrupt disabled but input buffer enabled
	    // <PORT_ISC_BOTHEDGES_gc"> Sense Both Edges
	    // <PORT_ISC_RISING_gc"> Sense Rising Edge
	    // <PORT_ISC_FALLING_gc"> Sense Falling Edge
	    // <PORT_ISC_INPUT_DISABLE_gc"> Digital Input Buffer disabled
	    // <PORT_ISC_LEVEL_gc"> Sense low Level
	    PORT_ISC_INTDISABLE_gc);

	/* set the alternate pin mux */
	PORTMUX.CTRLB |= PORTMUX_TWI0_bm;

	I2C_0_init();
}

/**
 * \brief System initialization
 */
void system_init()
{
	mcu_init();

	/* PORT setting on PA3 */

	// Set pin direction to input
	GPIO2_set_dir(PORT_DIR_IN);

	GPIO2_set_pull_mode(
	    // <y> Pull configuration
	    // <id> pad_pull_config
	    // <PORT_PULL_OFF"> Off
	    // <PORT_PULL_UP"> Pull-up
	    PORT_PULL_OFF);

	/* PORT setting on PB3 */

	// Set pin direction to output
	LED1_set_dir(PORT_DIR_OUT);

	LED1_set_level(
	    // <y> Initial level
	    // <id> pad_initial_level
	    // <false"> Low
	    // <true"> High
	    false);

	/* PORT setting on PB4 */

	// Set pin direction to output
	LED2_set_dir(PORT_DIR_OUT);

	LED2_set_level(
	    // <y> Initial level
	    // <id> pad_initial_level
	    // <false"> Low
	    // <true"> High
	    false);

	/* PORT setting on PB5 */

	// Set pin direction to output
	LED3_set_dir(PORT_DIR_OUT);

	LED3_set_level(
	    // <y> Initial level
	    // <id> pad_initial_level
	    // <false"> Low
	    // <true"> High
	    false);

	/* PORT setting on PC1 */

	// Set pin direction to output
	LED4_set_dir(PORT_DIR_OUT);

	LED4_set_level(
	    // <y> Initial level
	    // <id> pad_initial_level
	    // <false"> Low
	    // <true"> High
	    false);

	/* PORT setting on PC2 */

	// Set pin direction to output
	LED5_set_dir(PORT_DIR_OUT);

	LED5_set_level(
	    // <y> Initial level
	    // <id> pad_initial_level
	    // <false"> Low
	    // <true"> High
	    false);

	/* PORT setting on PC3 */

	// Set pin direction to output
	LED6_set_dir(PORT_DIR_OUT);

	LED6_set_level(
	    // <y> Initial level
	    // <id> pad_initial_level
	    // <false"> Low
	    // <true"> High
	    false);

	CLKCTRL_init();

	Timer_init();
	
	TIMER_1_initialization();

	CPUINT_init();

	SLPCTRL_init();

	I2C_0_initialization();

	BOD_init();
}

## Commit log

2019-07-24 Adding initial hardware design files
    [laser-theremin.dxf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]
2019-07-24 Updated README.md Moved panel to gerber directory Fixed case on images directory
    [laser-theremin.dxf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]
